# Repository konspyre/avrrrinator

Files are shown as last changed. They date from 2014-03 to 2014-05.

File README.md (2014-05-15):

# avrrrinator

These are the Eagle source files for the Avrrrinator, a Bus Pirate 3 to AVR ISP adapter. Instead of running a rats nest of wiring to the Bus Pirate for programming, these adapters break everything out into the standard 6-pin ISP connector available on many boards. 

A cable connection is all that is required to begin programming your board using the Bus Pirate and avrdude.

### Which should I choose?

#### [Avrrrinator Rev. A](hardware/revA)

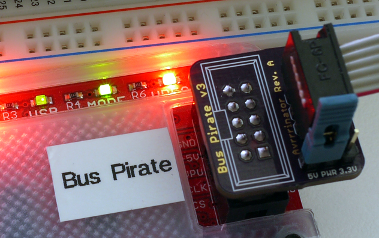
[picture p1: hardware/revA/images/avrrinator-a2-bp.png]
Avrrrinator Rev A2


Straight Bus Pirate to AVR breakout with 5v/3.3v selection. No logic level
translation. Simple and works.

#### [Avrrrinator Rev. B](hardware/revB)

Revision B isn't a program-many-AVRs-at-once board\*, but lets you connect more than one AVR for individual programming. This is great for prototyping and flipping different bits on two identical circuits (low power projects, debugging, etc). 

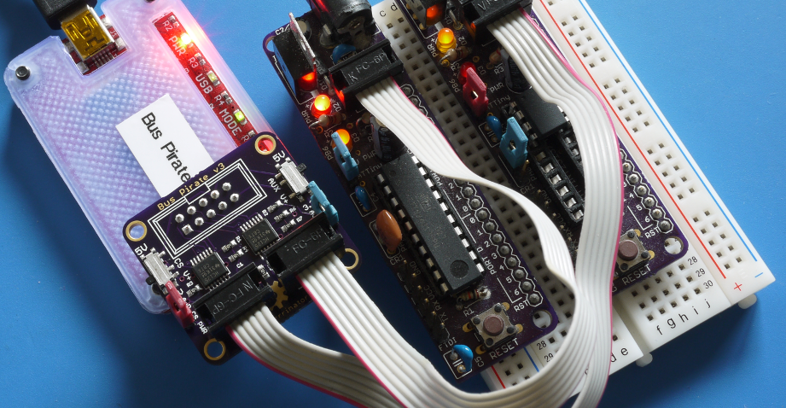
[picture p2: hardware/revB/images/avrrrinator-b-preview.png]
Avrrrinator Rev B1


The Eagle files are available for Rev B. Not much will change since this ended up being more of a toy/experimental project than anything else. It works though!

\* Saying parallel would be confusing since old-school parallel port AVR programmers are out there (and with many likely still in use).

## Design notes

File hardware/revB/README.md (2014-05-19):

# Avrrrinator Rev. B
Avrrrinator Rev B1

### Fabrication (OSHPark shared project)

[Shared at OSHPark](https://oshpark.com/shared_projects/C2GnBJb3)

### Bill of Materials for Revision B
| Quantity | Description | Part number | Board Placement |
| --- | --- | --- | --- |
| 2 | 6 pin AVR ISP header | [Mouser: 517-9612066404AR](http://www.mouser.com/Search/Refine.aspx?Keyword=517-9612066404AR) | ISP CS and ISP AUX (6-pin through-hole footprints) |
| 2 | 0.1"/2.54mm breakaway header (2 pins needed for each) | 36-pin header: [Mouser: 649-68004-236](http://www.mouser.com/Search/Refine.aspx?Keyword=649-68004-236) | AVR CS PWR/AUX PWR pins (two pins each) |
| 2 | Jumper/Power coupler | [Mouser: 151-8033-E](http://www.mouser.com/Search/Refine.aspx?Keyword=151-8033-E) (Red) / [Mouser: 151-8031-E](http://www.mouser.com/Search/Refine.aspx?Keyword=151-8031-E) (Blue) | Jumpers on two-pin CS/AUX power normally placed to close |
| 1 | 10 pin PCB to Bus Pirate 3 female connector | [Mouser: 517-8510-4500PL](http://www.mouser.com/Search/Refine.aspx?Keyword=517-8510-4500PL) | Bus Pirate v3 header (bottom side with keyed slot matching outline) | 
| 2 | AVR ISP cable (6-pin to 6-pin f/f)\* | [Adafruit: PID 371](http://www.adafruit.com/products/371) | N/A |
| 2 | 0603 imperial 0.1µF capacitors | [Mouser: VJ0603Y104JXJPW1BC](http://www.mouser.com/Search/Refine.aspx?Keyword=VJ0603Y104JXJPW1BC) | C1 and C2 |
| 2 | 74HC125 buffers | [Mouser: SN74HC125PWR](http://www.mouser.com/Search/Refine.aspx?Keyword=SN74HC125PWR) | IC1 and IC2 - Match silkscreen circle orientor with IC's |
| 8 | 0603 imperial 10k ohm resistors | [Mouser: CR0603-JW-103GLF](http://www.mouser.com/Search/Refine.aspx?Keyword=CR0603-JW-103GLF) | R1, R2, R3, R4, R5, R6, R7, R8 (or R1-R8) |
| 2 | Surface mount power selection switch | [Mouser](http://www.mouser.com/Search/Refine.aspx?Keyword=PCM12SMTR)/[Digikey](http://www.digikey.com/product-detail/en/PCM12SMTR/401-2016-1-ND/)/[Newark](http://www.newark.com/c-k-components/pcm12smtr/switch-slide-spdt-300ma-through/dp/28C3147): PCM12SMTR | Top and bottom switches (they should fit into the non-plated drills and be somewhat flush with the board | 

* Colorful (and somewhat odd) alternative at [Digikey P/N: SAM8734-ND](http://www.digikey.com/product-detail/en/IDSD-03-D-06.00-T/SAM8734-ND/3476372). Mouser used to sell a proper 6-pin IDC cable, but they don't anymore (or it is really well hidden).

### Alternative connector for Bus Pirate to Avrrrinator Rev. B

Exchanging the Bus Pirate <-> Avrrrinator connector for these two items allows the Avrrrinator PCB to be located further away from the Bus Pirate. This was the method used in early prototypes (it isn't recommended since things just end up flopping everywhere).

| Quantity | Description | Part number |
| --- | --- | --- |
| 1 | 10-pin IDC cable | [Adafruit: 370](adafru.it/370) |
| 1 | 10-pin box connector | [Mouser: 538-90130-1110](http://www.mouser.com/Search/Refine.aspx?Keyword=5538-90130-1110) |

### More information/boring blog post

[http://open.konspyre.org/avrb](http://open.konspyre.org/avrb)

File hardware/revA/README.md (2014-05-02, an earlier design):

# Avrrrinator Rev. A

This is a single-ended AVR ISP breakout for use with the Bus Pirate v3. It connects directly to the Bus Pirate via a keyed header.

AVrrrinator Rev A2

There is a voltage selection jumper that allows simple switching between the 5v and 3.3v rails provided by the Bus Pirate. Note that while this board allows voltage selection between the Bus Pirate's provided power
rails (5V or 3.3V) that the logic levels are fixed at 3.3v during programming.

## Use

1. Install avrdude

2. Install/plug in your Bus Pirate 3 and make sure that it works on your system. [Bus Pirate AVR programming guide](http://dangerousprototypes.com/docs/Bus_Pirate_AVR_Programming)

3. Plug in all cables, attach the Avrrrinator PCB to the Bus Pirate (note orientation of all cabling before applying power). 
 
4. Set the voltage jumper to your desired level.

5. Write to your AVR breakouts with the following: `avrdude -v -p attiny4313 -c buspirate -P /dev/ttyUSB0 -U flash:w:blinky4313.hex`

Replace: `attiny4313`, `/dev/ttyUSB0`, and `blinky4313.hex` with values from your own environment. 

### Bill of Materials for Revision A
| Quantity | Description | Part number |
| --- | --- | --- |
| 1 | 6 pin AVR ISP header | [Mouser: 517-9612066404AR](http://www.mouser.com/Search/Refine.aspx?Keyword=517-9612066404AR) |
| 1 | 3 pin breakaway header | 36-pin header: [Mouser: 649-68004-236](http://www.mouser.com/Search/Refine.aspx?Keyword=649-68004-236) / Alternative (3-pin, untested!): [Mouser: 571-1031853](http://www.mouser.com/Search/Refine.aspx?Keyword=571-1031853) |
| 1 | Jumper/Power selector | [Mouser: 151-8033-E](http://www.mouser.com/Search/Refine.aspx?Keyword=151-8033-E) (Red) / [Mouser: 151-8031-E](http://www.mouser.com/Search/Refine.aspx?Keyword=151-8031-E) (Blue) |
| 1 	 | 10 pin PCB to Bus Pirate 3 female connector | [Mouser: 517-8510-4500PL](http://www.mouser.com/Search/Refine.aspx?Keyword=517-8510-4500PL)
| 1 	 | AVR ISP cable (6-pin to 6-pin f/f)\* | [Adafruit: PID 371](http://www.adafruit.com/products/371)

* Colorful (and somewhat odd) alternative at [Digikey P/N: SAM8734-ND](http://www.digikey.com/product-detail/en/IDSD-03-D-06.00-T/SAM8734-ND/3476372). Mouser used to sell a proper 6-pin IDC cable, but they don't anymore (or it is really well hidden).

## Fabrication

**Please note**: Due to the extra I/O pins, this breakout is not readily compatible with a **v4** Bus Pirate.

Get these made at OSHPark by [clicking here](https://oshpark.com/shared_projects/tvIUA78A).

## Assembly

1. Snap 3 pins off of the breakaway header and solder it into the voltage selection area.
2. Solder in the 6-pin ISP header
3. Solder in the Bus Pirate mating header (10 pins).

#### Assembly notes

Most of the difficulty in assembling this board is soldering the 10-pin mating header. There is an alignment line silkscreened on the back
to assist with getting it straight (and in the right orientation). To get a decent result, try soldering one corner pin in, aligning it with 
the silk, and then tacking in an opposite corner.
 
The other headers (power select, 6-pin ISP header) can also be placed with decent precision using this method.

## Todo

Complete assembly writeup (for the brave, just slot in all the components where they fit).

## Notable changes

Revision A2: Silkscreen updates (mostly written on the mask layer), along with BOM change to a direct mounting header.

Revision A1: Initial release. [Previous documentation and BOM](http://open.konspyre.org/blog/2013/01/23/the-avrrrinator-revision-a/).

## Licensing

CC0 Public Domain

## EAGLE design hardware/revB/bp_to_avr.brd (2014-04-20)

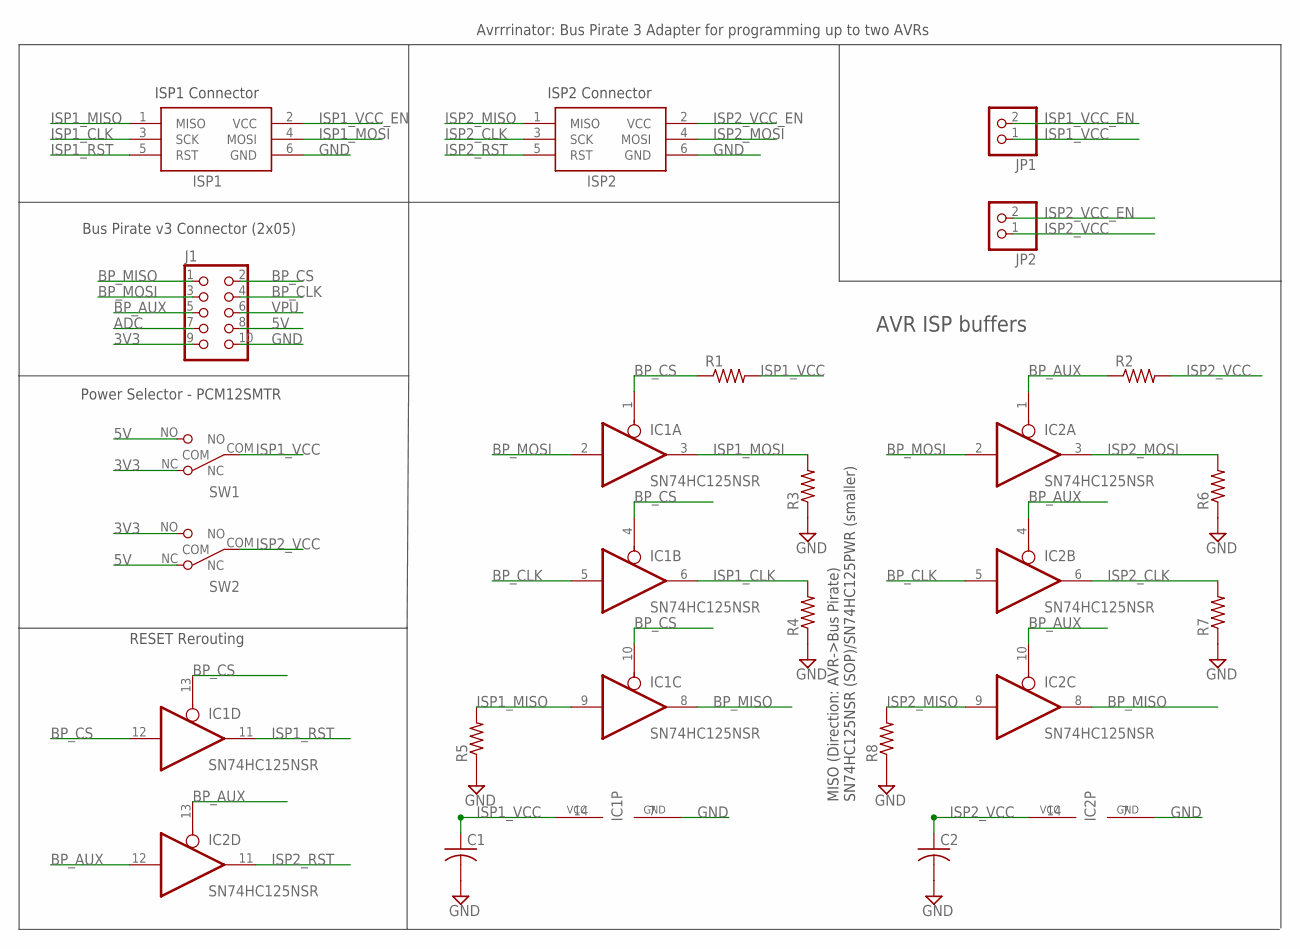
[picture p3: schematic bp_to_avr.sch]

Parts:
C1, C2: C-USC0603; C0603
IC1, IC2: SN74HC125NSR; AVRRRINATOR-PWR
ISP1, ISP2: AVRRRINATOR-AVRISP-6PIN-6; AVRRRINATOR-AVRISP-6PIN
J1: CON_HEADER_2X05-PTH+SHROUDED_B; PINSHRD_PTH_2X05B
JP1, JP2: HEADER-1X2ROUND; 1X02_ROUND
R1, R2, R3, R4, R5, R6, R7, R8: R-US_R0603; R0603
SW1, SW2: SW_SLIDE; SLIDE_SWITCH_SMD

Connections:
3V3: J1.9, SW1.NC, SW2.NO
5V: J1.8, SW1.NO, SW2.NC
ADC: J1.7
BP_AUX: IC2.1 (OE), IC2.4 (OE), IC2.10 (OE), IC2.12 (I), IC2.13 (OE), J1.5, R2.1
BP_CLK: IC1.5 (I), IC2.5 (I), J1.4
BP_CS: IC1.1 (OE), IC1.4 (OE), IC1.10 (OE), IC1.12 (I), IC1.13 (OE), J1.2, R1.1
BP_MISO: IC1.8 (O), IC2.8 (O), J1.1
BP_MOSI: IC1.2 (I), IC2.2 (I), J1.3
GND: C1.2, C2.2, IC1.7 (GND), IC2.7 (GND), ISP1.6 (GND), ISP2.6 (GND), J1.10, R3.1, R4.1, R5.1, R6.1, R7.1, R8.1
ISP1_CLK: IC1.6 (O), ISP1.3 (SCK), R4.2
ISP1_MISO: IC1.9 (I), ISP1.1 (MISO), R5.2
ISP1_MOSI: IC1.3 (O), ISP1.4 (MOSI), R3.2
ISP1_RST: IC1.11 (O), ISP1.5 (RST)
ISP1_VCC: C1.1, IC1.14 (VCC), JP1.1, R1.2, SW1.COM
ISP1_VCC_EN: ISP1.2 (VCC), JP1.2
ISP2_CLK: IC2.6 (O), ISP2.3 (SCK), R7.2
ISP2_MISO: IC2.9 (I), ISP2.1 (MISO), R8.2
ISP2_MOSI: IC2.3 (O), ISP2.4 (MOSI), R6.2
ISP2_RST: IC2.11 (O), ISP2.5 (RST)
ISP2_VCC: C2.1, IC2.14 (VCC), JP2.1, R2.2, SW2.COM
ISP2_VCC_EN: ISP2.2 (VCC), JP2.2
VPU: J1.6

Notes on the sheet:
Avrrrinator: Bus Pirate 3 Adapter for programming up to two AVRs
Power Selector - PCM12SMTR
Bus Pirate v3 Connector (2x05)
AVR ISP buffers
MISO (Direction: AVR->Bus Pirate) SN74HC125NSR (SOP)/SN74HC125PWR (smaller)
ISP1 Connector
ISP2 Connector
RESET Rerouting

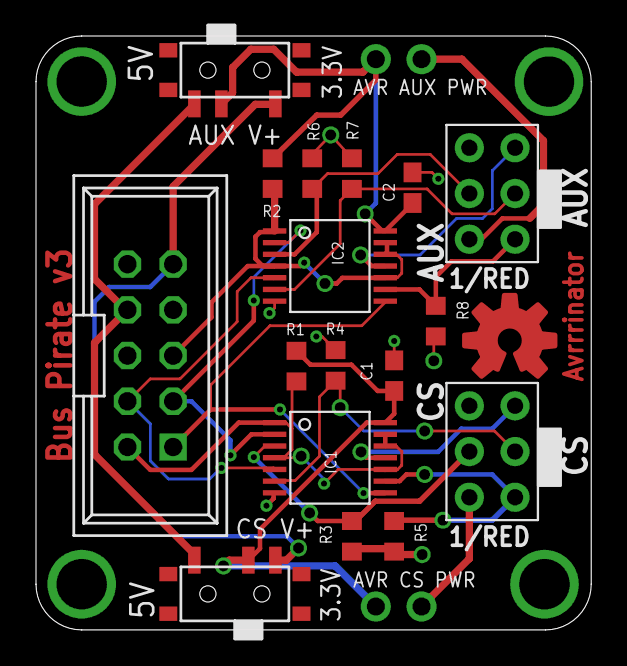
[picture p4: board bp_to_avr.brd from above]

Board: 2 copper layers, 30.8 x 33.0 mm, 20 parts (0 on the bottom side), 20 nets.

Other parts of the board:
U$1: ADAFRUIT_OSHWLOGO_TOP_0.2_NO_MASK

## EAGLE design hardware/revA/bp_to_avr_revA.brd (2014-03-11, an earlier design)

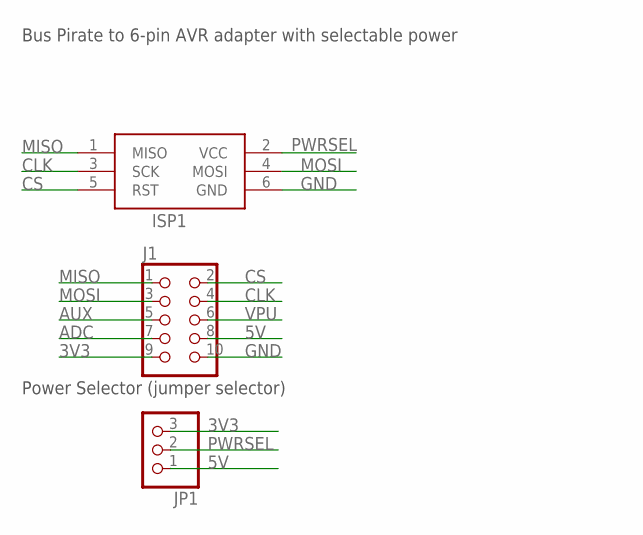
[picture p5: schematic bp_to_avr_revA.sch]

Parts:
ISP1: AVRISP-6; AVRISP
J1: CON_HEADER_2X05-PTH+SHROUDED_B; PINSHRD_PTH_2X05B
JP1: PINHD-1X3; 1X03

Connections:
3V3: J1.9, JP1.3
5V: J1.8, JP1.1
ADC: J1.7
AUX: J1.5
CLK: ISP1.3 (SCK), J1.4
CS: ISP1.5 (RST), J1.2
GND: ISP1.6 (GND), J1.10
MISO: ISP1.1 (MISO), J1.1
MOSI: ISP1.4 (MOSI), J1.3
PWRSEL: ISP1.2 (VCC), JP1.2
VPU: J1.6

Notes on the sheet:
Bus Pirate to 6-pin AVR adapter with selectable power
Power Selector (jumper selector)

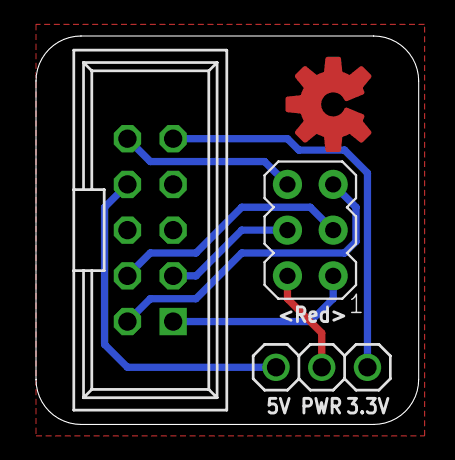
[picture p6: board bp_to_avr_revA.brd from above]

Board: 2 copper layers, 21.3 x 21.6 mm, 4 parts (0 on the bottom side), 8 nets.

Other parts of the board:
U$4: ADAFRUIT_OSHWLOGO_TOP_0.2_NO_MASK

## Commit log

2013-01-23 Add board layout & schematic files
    [bp_to_avr.brd, bp_to_avr.sch]
2013-01-23 Add board preview images
    These were generated by OSHPark's board preview system.
2014-03-11 Rename current revision files for historical continuity
    [bp_to_avr_revA.brd, bp_to_avr_revA.sch]
2014-03-11 Avrrrinator Rev. A cosmetic/BOM changes
    - Align OSHW logo w/PCB use direction + no mask
    - Has bottom alignment silk for bus pirate header underneath
    - Poly pour + mask text
    [bp_to_avr_revA.brd]
2014-03-11 Bill of Materials + README for Avrrrinator Rev. A
2014-03-11 Remove obsolete Rev A PCB previews
2014-03-11 revA: Add assembly steps
2014-03-12 Add board picture
2014-04-20 Add revB eagle board/schematic files
    Licensing: Creative Commons Attribution, Share-Alike license
    [bp_to_avr.brd, bp_to_avr.sch]
2014-05-04 Bill of Materials
2014-05-04 More fixes to BOM
